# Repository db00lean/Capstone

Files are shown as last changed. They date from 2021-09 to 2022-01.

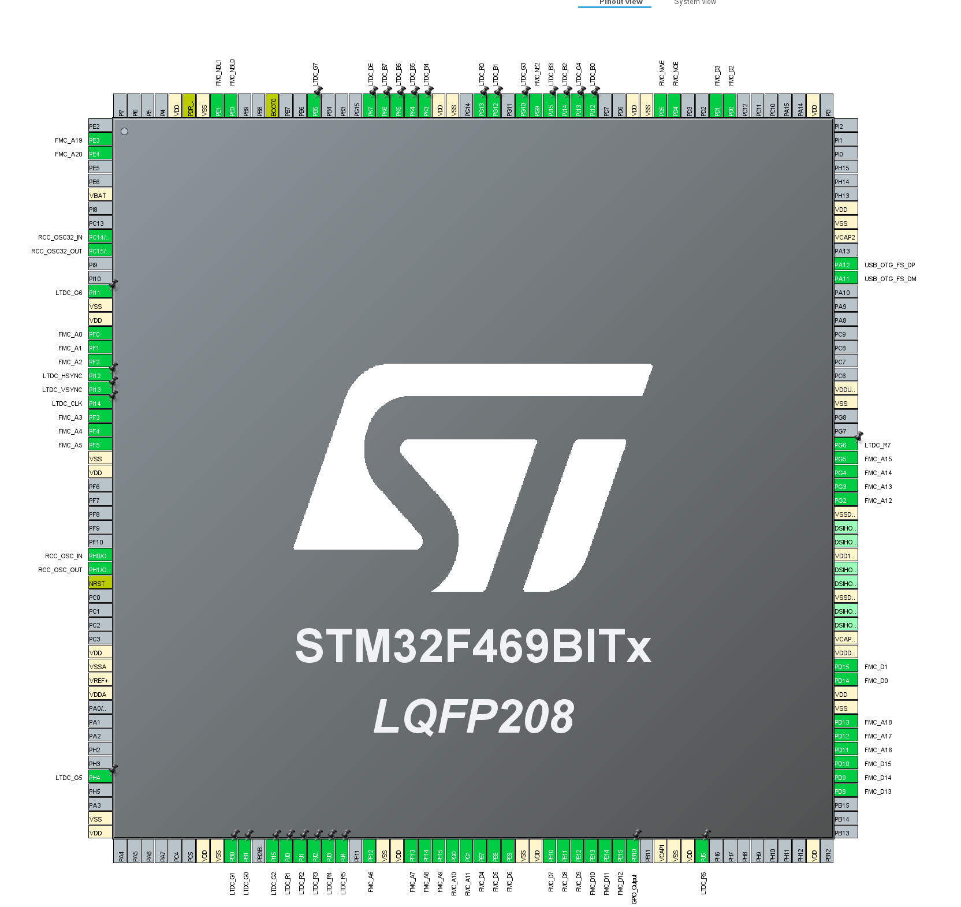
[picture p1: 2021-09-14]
Software/Resources/Pinout.PNG

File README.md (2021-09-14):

# Capstone
Fall 2021 Final Capstone Project

File System:
```
>Capstone
    >Software
        >Resources
        >CodeBase
    >Hardware
        >Library
            >Personal Library
            >Universal Converter Library
        >Resources
            >Datasheets
        >UniversalConverter
            > Altium Files
```

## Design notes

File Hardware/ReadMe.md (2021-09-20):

# Attention!
Please make sure all files upload, sometimes the drag and drop will neglect certain file extensions

Please do not change the file tree!

# Library:
Parts libraries used in Univseral Converter Altium project. These parts libraries contain all symbol and footprint files.

To install open the .libPkg file in Altium which will automatically open all the other files

# Resources:
Useful documentation for all things relating to hardware. Contains files like Datasheets, websites, and diagrams.

# Universal Converter
Core Altium project containing all files for the PCB and schematics. Do not change file structure

# LTSpice Simulations
All information regarding the research, planning, and execution for designing the power conversion circuitry around the LT3790 buck-boost converter.

Please Update Revision Number in text file name!

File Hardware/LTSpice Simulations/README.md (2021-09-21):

The core functionality of this project lies within the LT3790 buck-boost converter, which allows for high efficiency buck and boost operations on an input source within a specified range. To test the functionality of the IC without creating several PCB revs, we decided to run simulations to ensure "normal" operation of our circuitry prior to ordering boards.

To run the simulation, install LTSpice on your machine and pull the file ```Capstone/hardware/LTSpice Simulations/LT3790_Rev_A.asc```. This is the base simulation file from Linear Technologies for the LT3790 converter. We will build upon this in future revs.

# Simulation Tasks
There are several subtasks within simulating the LT3790 needed to design a fully-functional system that meets our desired goal.

## Understanding The Datasheet
It is vital that all electrical hardware engineers understand the LT3790 datasheet. 
The datasheet is located at ```Capstone/hardware/resources/LT3790_datasheet.pdf```

## Switching Component Selection
For the most efficient operation within our specified ranges of input/output voltage and current, 
we must select appropriate switching MOSFETs and inductors with minimum Rdson and and high enough 
inductor SRF that our maximum switching frequency does not cause the inductor to self-resonate. More to come.

## Current/Voltage Limit Circuitry
The actual circuitry in this portion of the design will differ from the simulation, but we need
to understand how we can modify the voltage and current limits in real-time to adjust our output and 
effectively achieve the universal converter operation. If we can find a way to run code through the 
LTSpice simulation, we may be able to model how the firmware will integrate with the LT3790.

## External Converter Component Selection
A much easier task as we can use what is provided in the component selection portion of the datasheet to
select additional external components around the LT3790.

## Add A Second Converter
For dual-output, we need to add a second converter in the output path of the first. More to come after
fully simulating the base design.

## Add Remaining External Components
Aside from the MCU and firmware related components, we also can simulate the other ICs and components within 
the main power path. More to come.

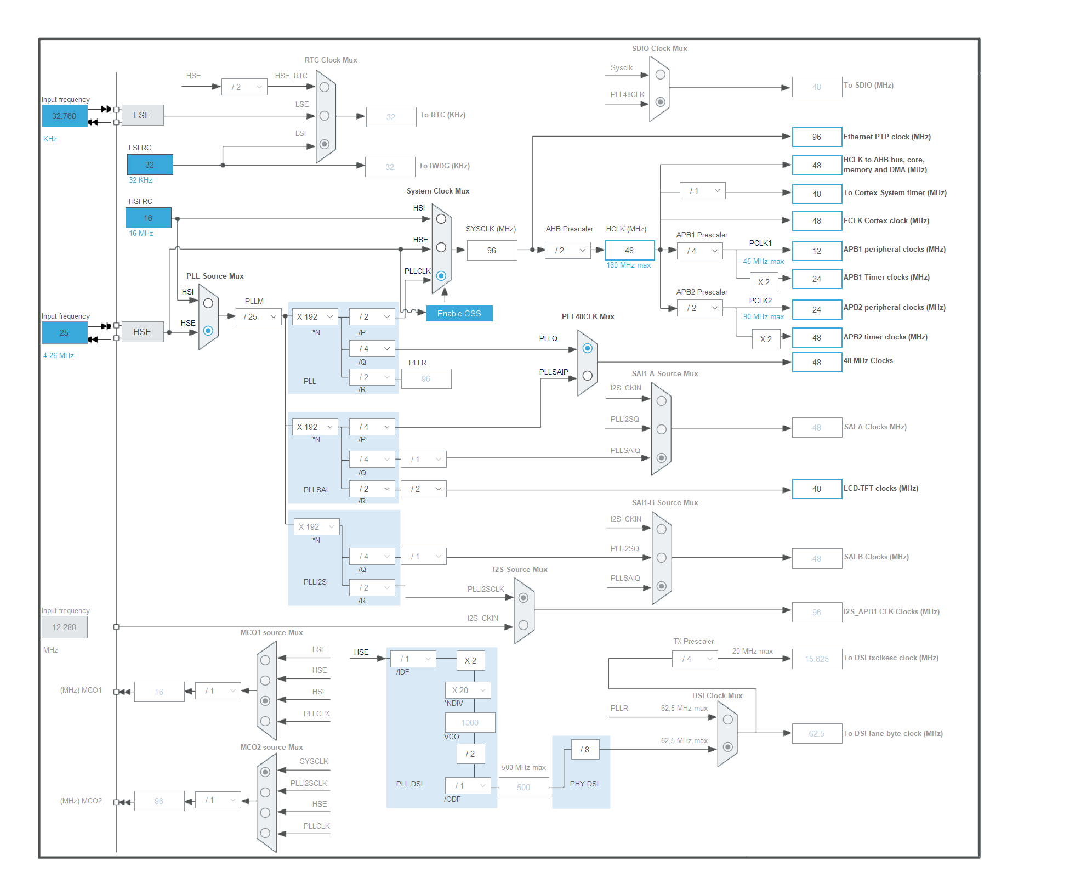
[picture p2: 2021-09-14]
Software/Resources/ClockDiagram.PNG

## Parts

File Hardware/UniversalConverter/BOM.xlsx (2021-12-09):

Part Number | Manufacturer | Description | Reference | Price | per board | STOCK | Link
SQJA80EP-T1_GE3TR-ND | Vishay Siliconix | MOSFET N-CH 80V 60A PPAK SO-8 |  | $1.26 | 11 | 10 | https://www.digikey.com/en/products/detail/vishay-siliconix/SQJA80EP-T1-GE3/6708932
SK58L-TPMSTR-ND | Micro Commercial Co | DIODE SCHOTTKY 80V 5A DO214AB |  | $0.48 | 4 | 5
LT3790IFE#TRPBF | Linear Tech | IC REG CTRLR BUCK-BOOST 38TSSOP |  | $11.53 | 2 | 3
HMK325BJ475KM-PE | Taiyo Yuden | CAP CER 4.7UF 100V X5R 1210 |  | $1.08 | 30 | 12
1727-4817-2-ND |  | DIODE SCHOTTKY 100V 250MA SOD323 |  | $0.38 | 4 | 3
732-2174-2-ND | Würth Elektronik | FIXED IND 6.8UH 18.5A 4.1MOHM SM |  | $5.53 | 2 | 2
296-44514-5-ND | Texas Instruments | IC REG BUCK ADJUSTABLE 3A 8SOPWR |  | $4.89 | 1 | 10
B380B-13-FDITR-ND | Diodes Incorporated | Diode Schottky 80 V 3A Surface Mount SMB |  | $0.91 | 1 | 0
732-1207-2-ND | Würth Elektronik | FIXED IND 8.2UH 6.25A 20MOHM SMD |  | $2.19 | 1 | 2
EEE-FN1K100XL | Panasonic Electronic Components | CAP ALUM 10UF 20% 80V SMD |  | $0.66 | 11 | 32
296-41943-5-ND | Texas Instruments | IC REG LIN 3.3V 500MA SOT223-6 |  | $4.49 | 1 | 5
LTC4359CMS8#TRPBFTR-ND | Analog Devices Inc. | IC OR CTRLR N+1 8MSOP |  | $4.61 | 4 | 3
LMP8480MME-S/NOPBTR-ND | Texas Instruments | IC CURR SENSE 1 CIRCUIT 8VSSOP |  | $3.34 | 3 | 6
CRF2512-FZ-R001ELFTR-ND | Bourns Inc. | RES 0.001 OHM 1% 2W 2512 |  | $0.67 | 3 | 3
MCP4017T-104E/LTTR-ND | Microchip Technology | IC DGT POT 100KOHM 128TAP SC70-6 |  | $0.63 | 2 | 5
10-EEE-FN1K470UVCT-ND | Panasonic Electronic Components | CAP ALUM 47UF 20% 80V SMD |  | $1.24 | 10 | 10
CRF2512-FZ-R004ELFTR-ND | Bourns Inc. | RES 0.004 OHM 1% 2W 2512 |  | $0.67 | 2 | 2
CRE2512-FZ-R005E-2TR-ND | Bourns Inc. | RES 0.005 OHM 1% 2W 2512 |  | $0.74 | 2 | 2
WSLH-.006TR-ND | Vishay Dale | RES 0.006 OHM 1% 2W 2512 |  | $1.76 | 2 | 2
RHM.007AUTR-ND | Rohm Semiconductor | RES 0.007 OHM 1% 2W 2512 |  | $0.70 | 2 | 2
CRE2512-FZ-R008E-2TR-ND | Bourns Inc. | RES 0.008 OHM 1% 2W 2512 |  | $0.74 | 2 | 2
YAG2163TR-ND | YAGEO | RES 0.009 OHM 1% 2W 2512 |  | $0.73 | 2 | 2
FSM6JSMATR | TE Connectivity | SWITCH TACTILE SPST-NO 0.05A 24V |  | $0.41 | 4
10118194-0001LF | Amphenol ICC (FCI) | CONN RCPT USB2.0 MICRO B SMD R/A |  | $0.45 | 1
RCLAMP0854P.TCTCT-ND | Semtech Corporation | TVS DIODE 5.5VWM 30VC SLP1616P6 |  | $0.94 | 1
296-15227-1-ND | Texas Instruments | IC DAC 12BIT V-OUT 10VSSOP |  | $8.30 | 1
PEC12R-4025F-S0024 | Bourns Inc. | ROTARY ENCODER MECHANICAL 24PPR |  | $1.31 | 1
497-4941-1-ND | STMicroelectronics | IC OPAMP GP 1 CIRCUIT SOT23-5 |  | $0.63 | 2
SK58L-TPMSCT-ND | Micro Commercial Co | DIODE SCHOTTKY 80V 5A DO214AB |  | $0.48 | 5
XC1846CT-ND | ECS Inc. | CRYSTAL 32.0000MHZ 8PF SMD |  | $1.01 | 1
300-8814-2-ND | Citizen Finedevice Co Ltd | CRYSTAL 32.7680KHZ 12.5PF SMD |  | $0.72 | 1
EG5468CT-ND | E-Switch | SWITCH TACTILE SPST-NO 0.05A 12V |  | $0.46 | 4
NHD-2.7-12864WDW3 | Newhaven Display Intl | LCD OLED GRAPHIC 128X64 WHT |  | $42.58 | 1
296-15227-1-ND | Texas Instruments | IC DAC 12BIT V-OUT 10VSSOP |  | $8.30 | 1
497-17515-ND | STMicroelectronics | IC MCU 32BIT 128KB FLASH 48LQFP |  | $6.32 | 1 | 4
111-0703-001 | Cinch Connectivity | CONN BIND POST KNURLED BLACK |  | $3.09 | 3
111-0702-001 | Cinch Connectivity | CONN BIND POST KNURLED RED |  | $3.09 | 3
541-0.0GCT-ND | Vishay Dale | RES SMD 0 OHM JUMPER 1/10W 0603 |  | $0.10 | 10
RMCF0603FT10K0CT-ND | Stackpole Electronics Inc | RES 10K OHM 1% 1/10W 0603 |  | $0.10 | 10
P200KGCT-ND | Panasonic Electronic Components | RES SMD 200K OHM 5% 1/10W 0603 |  | $0.10 | 10
445-5663-1-ND | TDK Corporation | CAP CER 0.022UF 50V X7R 0603 |  | $0.10 | 5
1276-CL10B104KB8NNNLCT-ND | Samsung Electro-Mechanics | CAP CER 0.1UF 50V X7R 0603 |  | $0.10 | 15
13-RE0603FRE071KLCT-ND | YAGEO | RES SMD 1K OHM 1% 1/10W 0603 |  | $0.10 | 5
641-1713-1-ND | Comchip Technology | DIODE SCHOTTKY 60V 1A DO214AA |  | $0.35 | 3
RMCF0603FT49K9CT-ND | Stackpole Electronics Inc | RES 49.9K OHM 1% 1/10W 0603 |  | $0.10 | 2
311-17.8KHRCT-ND | YAGEO | RES 17.8K OHM 1% 1/10W 0603 |  | $0.10 | 2
13-RE0603FRE07100KLCT-ND | YAGEO | RES SMD 100K OHM 1% 1/10W 0603 |  | $0.10 | 10
1763-1218-ND | Knowles Novacap | CAP CER 0.1UF 50V X7R 0805 EPOXY |  | $1.21 | 2
478-10560-1-ND | KYOCERA AVX | CAP CER 5000PF 50V X7R 0805 |  | $0.30 | 2
CR0603-FX-4321ELFCT-ND | Bourns Inc. | RES SMD 4.32K OHM 1% 1/10W 0603 |  | $0.10 | 2
311-1057-1-ND | YAGEO | CAP CER 8PF 50V C0G/NPO 0603 |  | $0.10 | 2

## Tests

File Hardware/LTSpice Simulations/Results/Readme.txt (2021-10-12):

The Inductor/Switching Frequency simulations are designed as follows:

Input: 5V
Output: 60V

Switching Frequencies of 200KHz to 700KHz in 100KHz intervals will be tested by changing the value
of the resistor on the Rt pin. The inductor will remain constant for each set of frequency tests.

A higher switching frequency should allow smaller inductor/capacitor values at the cost of increased switching losses and gate driving current.

A lower switching frequency should give better performance at the cost of large component sizes.

Required Plots:

-Output Voltage: Larger inductor values arise from lower switching frequencies, but have a direct effect on the ripple current.

-Gate Currents: Higher Switching frequencies will create larger gate driving currents, so each plots needs to show the gate currents of each of the four Power MOSFETs. These need to be tested and ensured that they're below the maximum specification of the FETs we purchased.

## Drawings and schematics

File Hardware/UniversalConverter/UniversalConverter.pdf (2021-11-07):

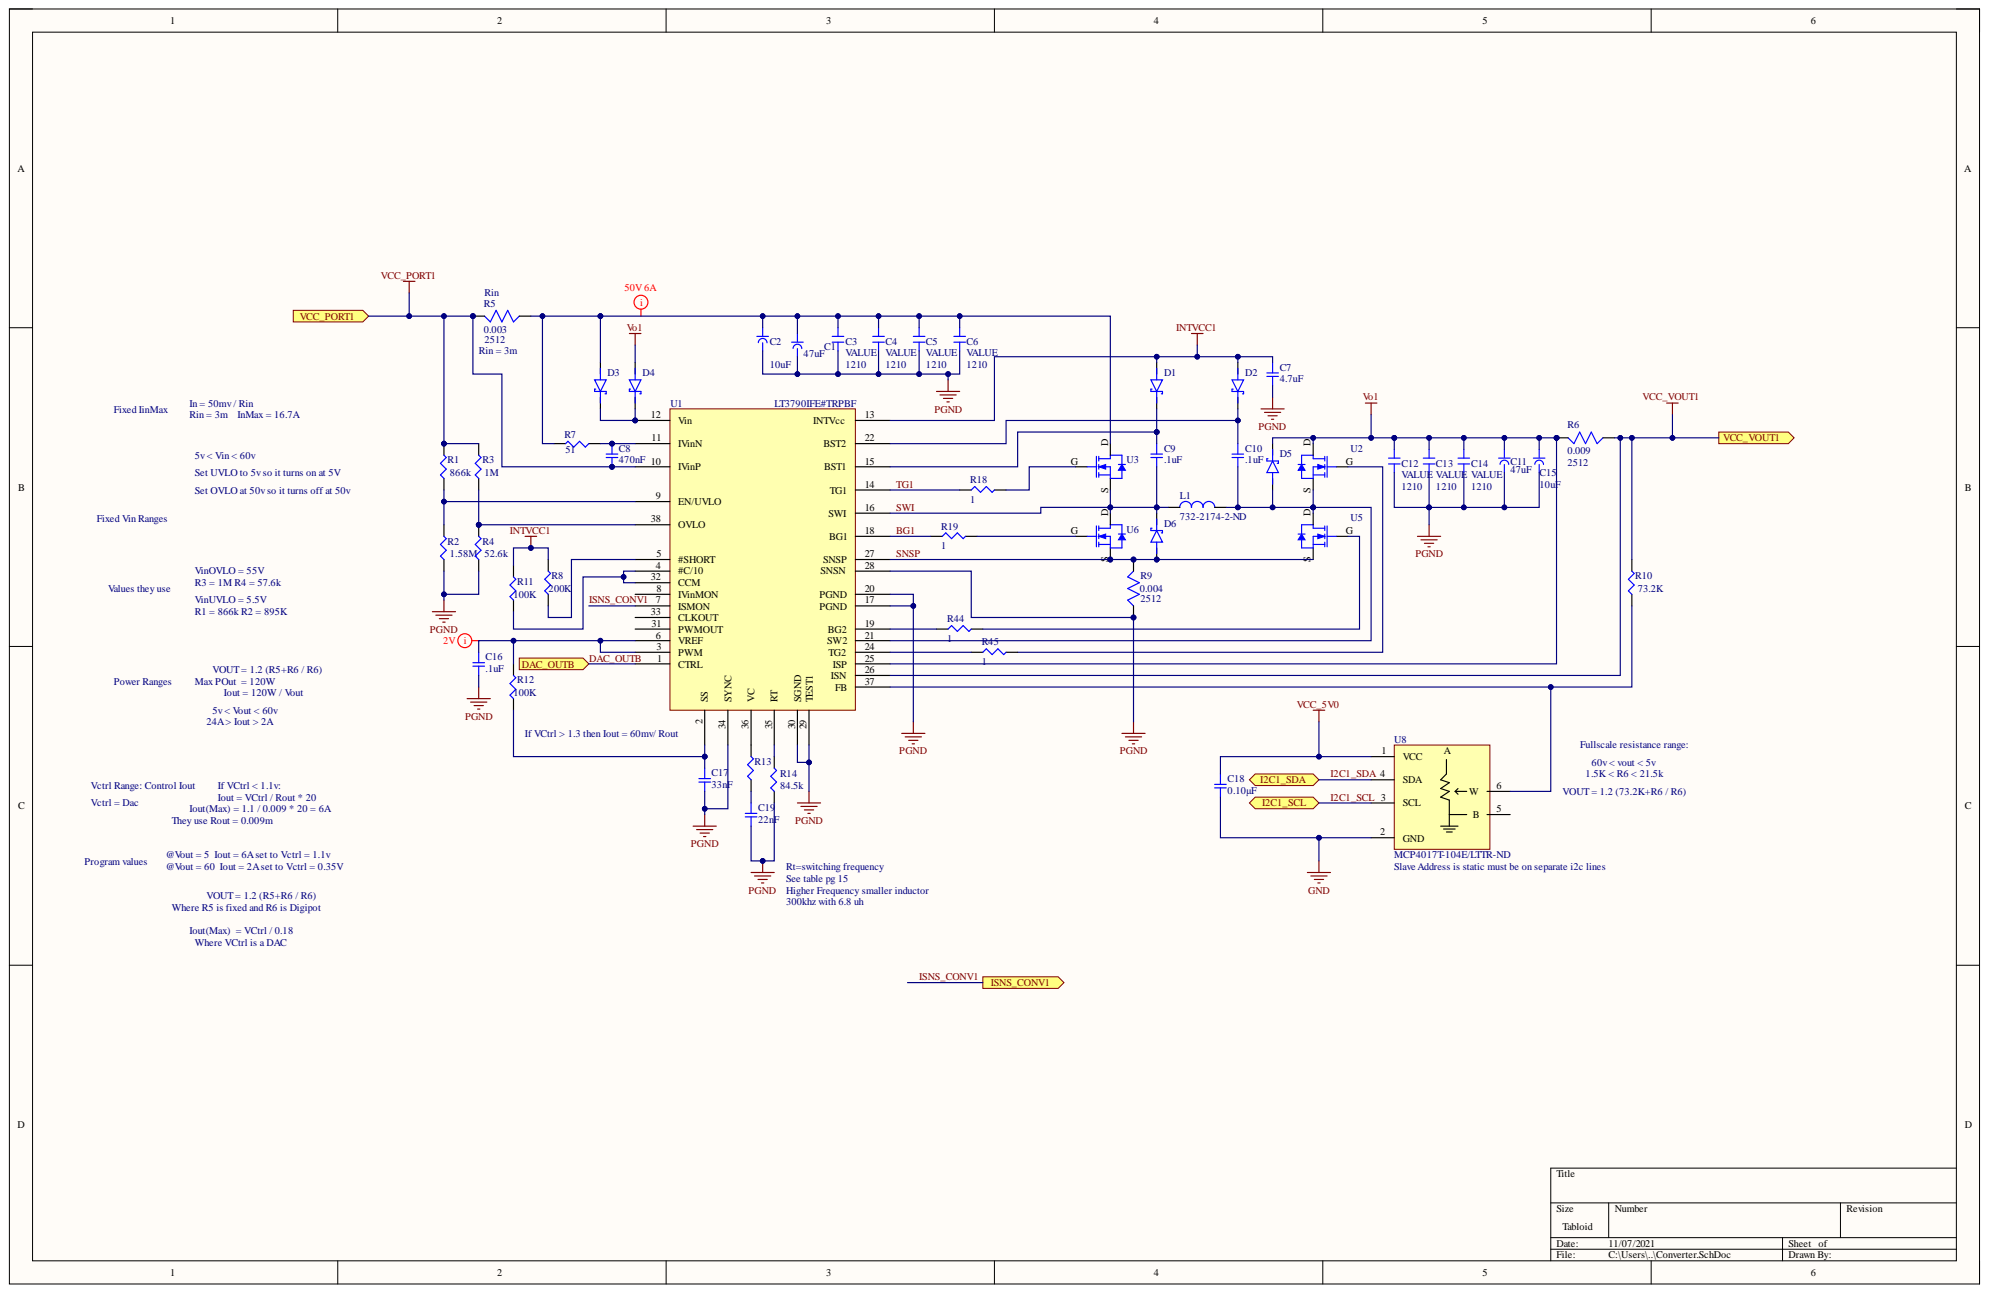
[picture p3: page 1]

In = 50mv / Rin Fixed IinMax

Set UVLO to 5v so it turns on at 5V

Set OVLO at 50v so it turns off at 50v

INTVCC1 | #SHORT 5

OVLO 38

VCC_5V0

If VCtrl > 1.3 then Iout = 60mv/ Rout

I2C1_SDA | SDA 4

Vctrl Range: Control Iout

@Vout = 5 Iout = 6Aset to Vctrl = 1.1v
@Vout = 60 Iout = 2Aset to Vctrl = 0.35V

MCP4017T-104E/LTTR-ND
Slave Address is static must be on separate i2c lines

Rt=switching frequency
See table pg 15
Higher Frequency smaller inductor
300khz with 6.8 uh

Where R5 is fixed and R6 is Digipot

Iout(Max) = VCtrl / 0.18
Where VCtrl is a DAC

Size Tabloid | Number | Revision

Date: 11/07/2021 | Sheet of
File: C:\Users\..\Converter.SchDoc | Drawn By:

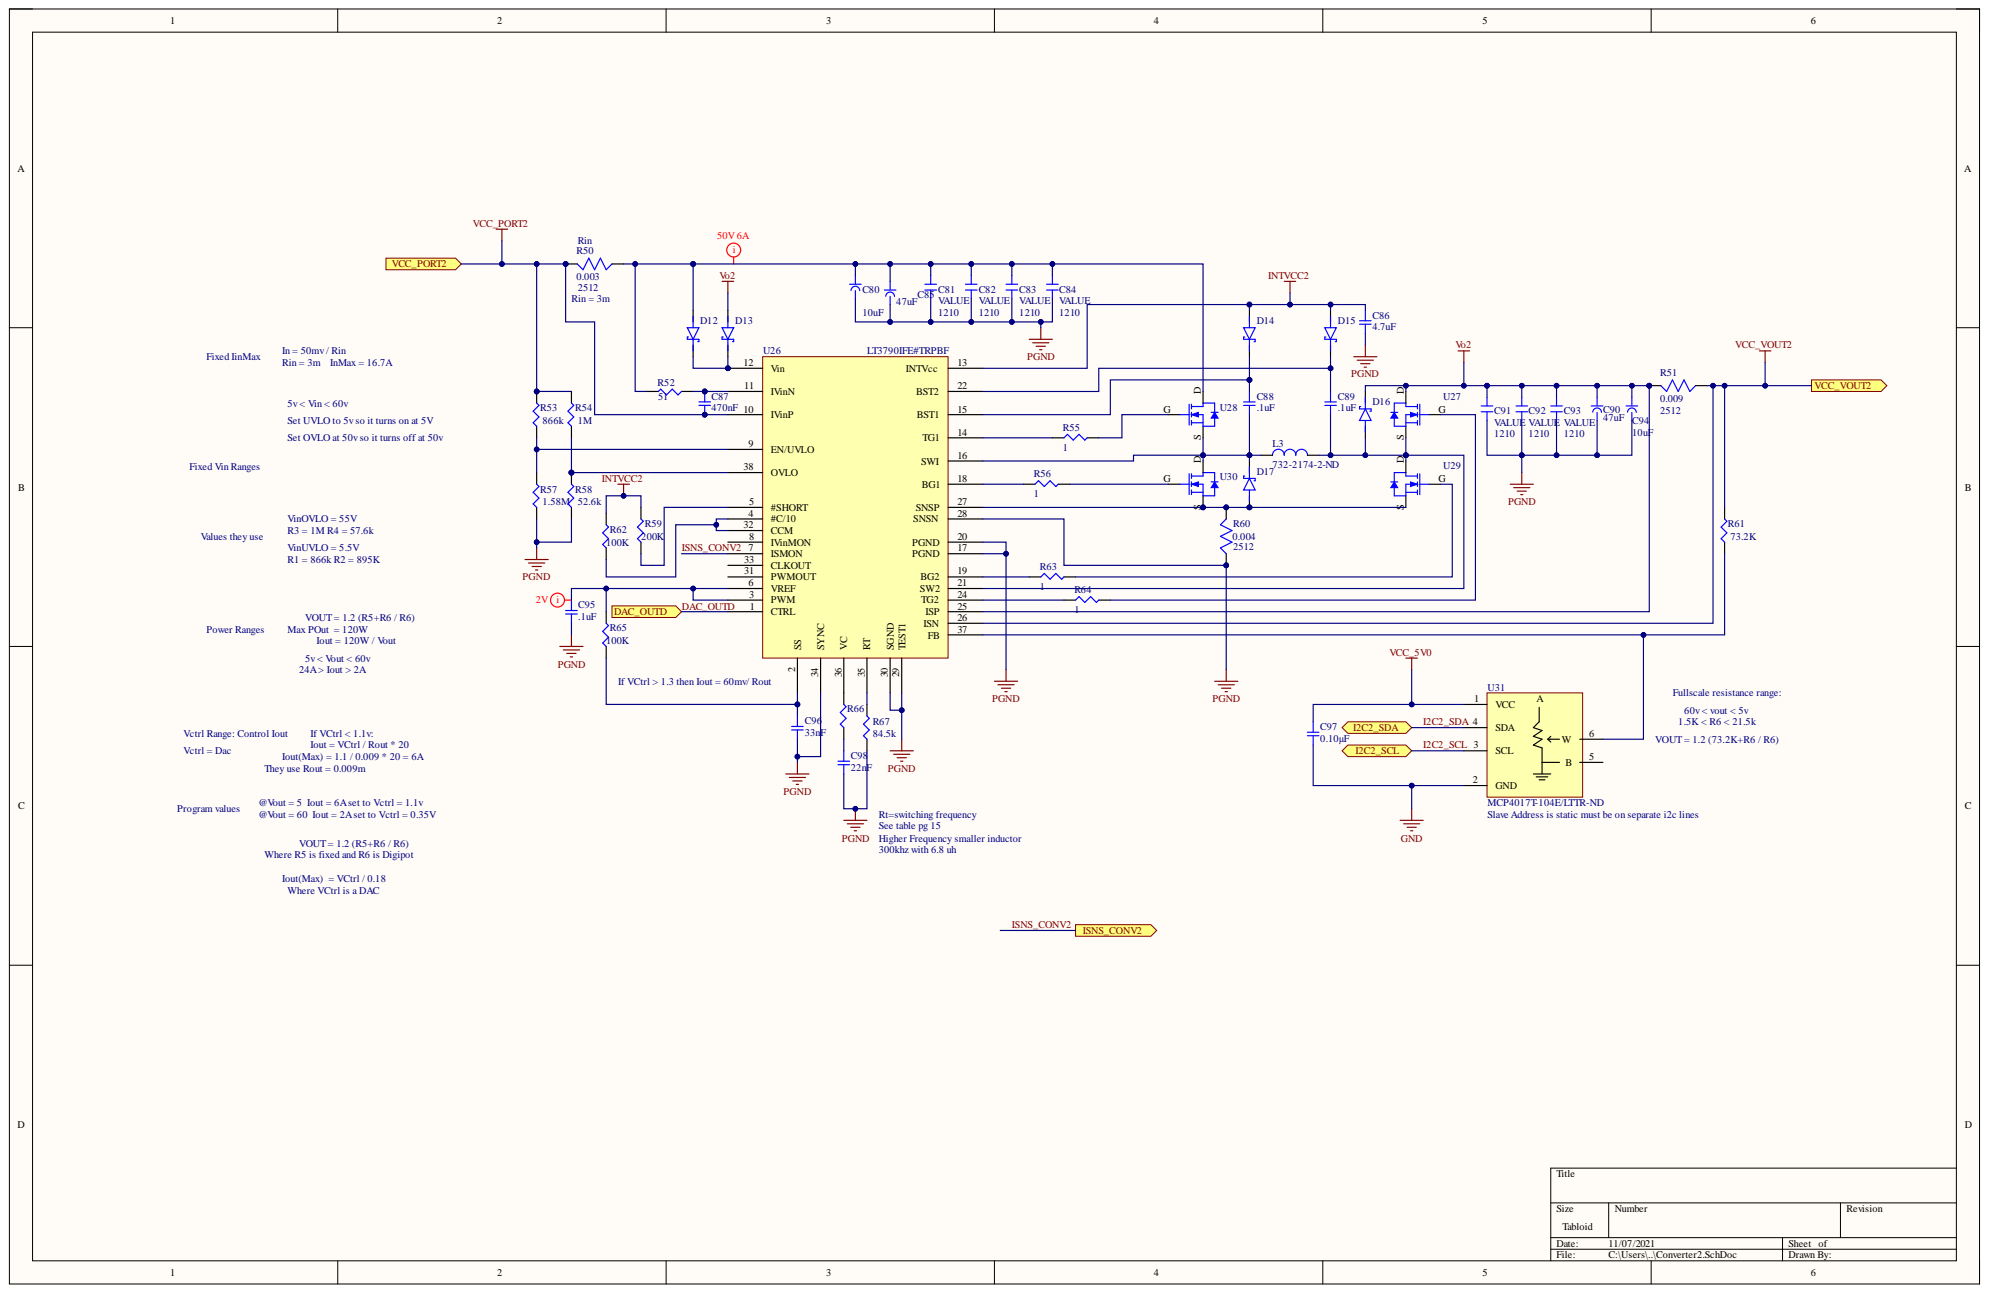
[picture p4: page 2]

In = 50mv / Rin Fixed IinMax

Set UVLO to 5v so it turns on at 5V

Set OVLO at 50v so it turns off at 50v

VCC_5V0

If VCtrl > 1.3 then Iout = 60mv/ Rout

Vctrl Range: Control Iout

I2C2_SDA | SDA 4

@Vout = 5 Iout = 6Aset to Vctrl = 1.1v
@Vout = 60 Iout = 2Aset to Vctrl = 0.35V

Rt=switching frequency
See table pg 15
Higher Frequency smaller inductor
300khz with 6.8 uh

MCP4017T-104E/LTTR-ND
Slave Address is static must be on separate i2c lines

Where R5 is fixed and R6 is Digipot

Iout(Max) = VCtrl / 0.18
Where VCtrl is a DAC

Size Tabloid | Number | Revision

Date: 11/07/2021 | Sheet of
File: C:\Users\..\Converter2.SchDoc | Drawn By:

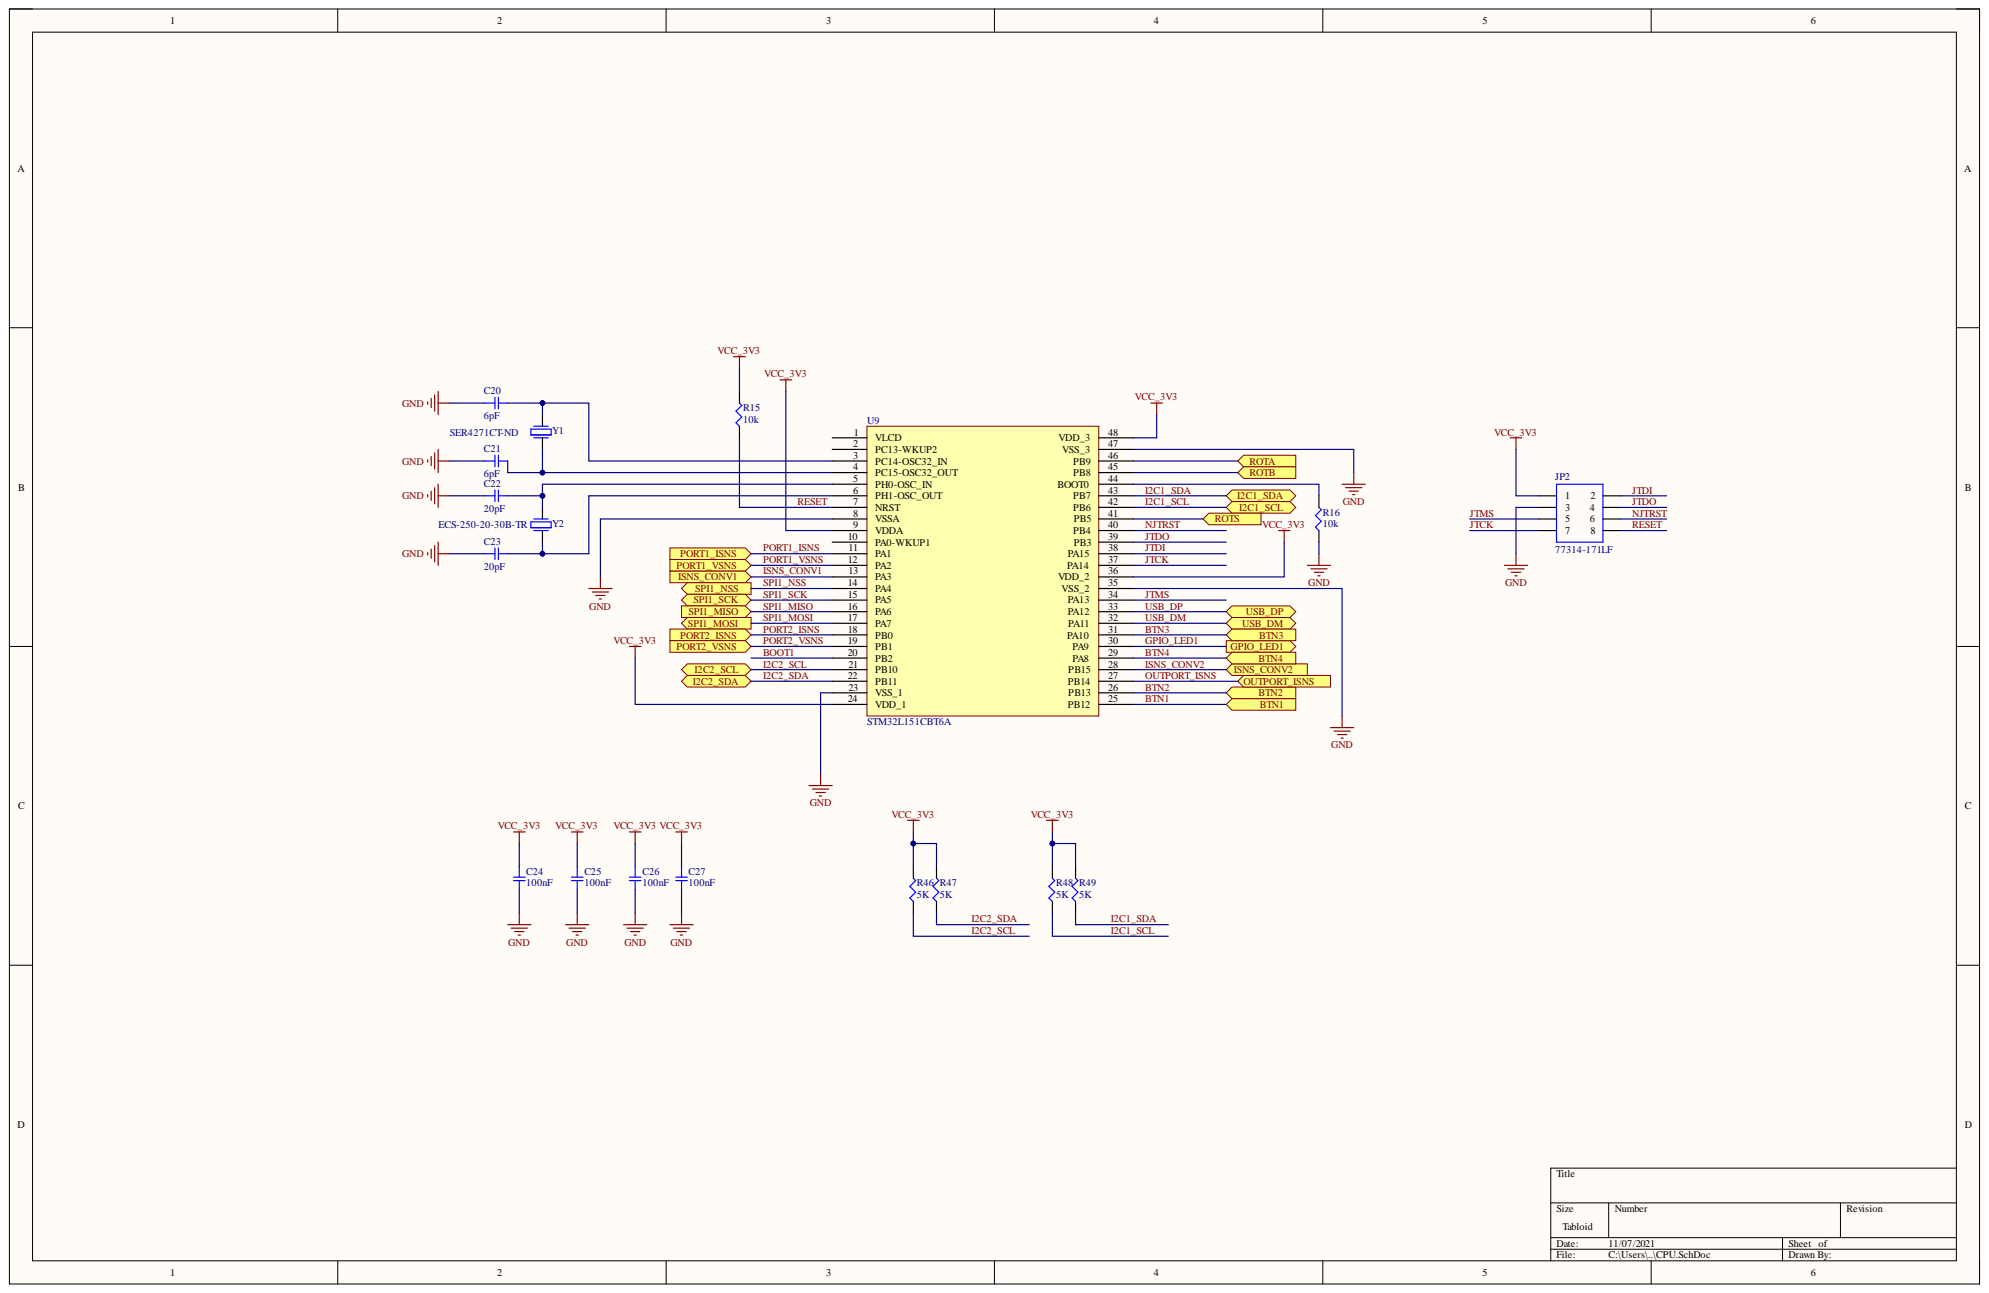
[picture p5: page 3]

2 | | 4 7
3 | | 4 6 4 5 | R O TA
5 | | 4 4

J TMS U S B _ D P U S B _ D P U S B _ D M U S B _ D M B TN 3 B TN 3 G P I O _ L E D 1 G P I O _ L E D 1 B TN 4 4 I S N S _ C O N V2 O U TP O RT_ I S N S I S N S _ C O N V2 O U TP O RT_ I S N S B TN 2 B TN 1 B TN 2 B TN 1

S i z e Tab l o i d | N u mb e r | R e vi s i o n

D at e : 1 1 / 0 7 / 2 0 2 1 | S h e e t o f
Fi l e : C : \ U s e r s \ . . \ C P U . S c hD o c | D r awn B y :

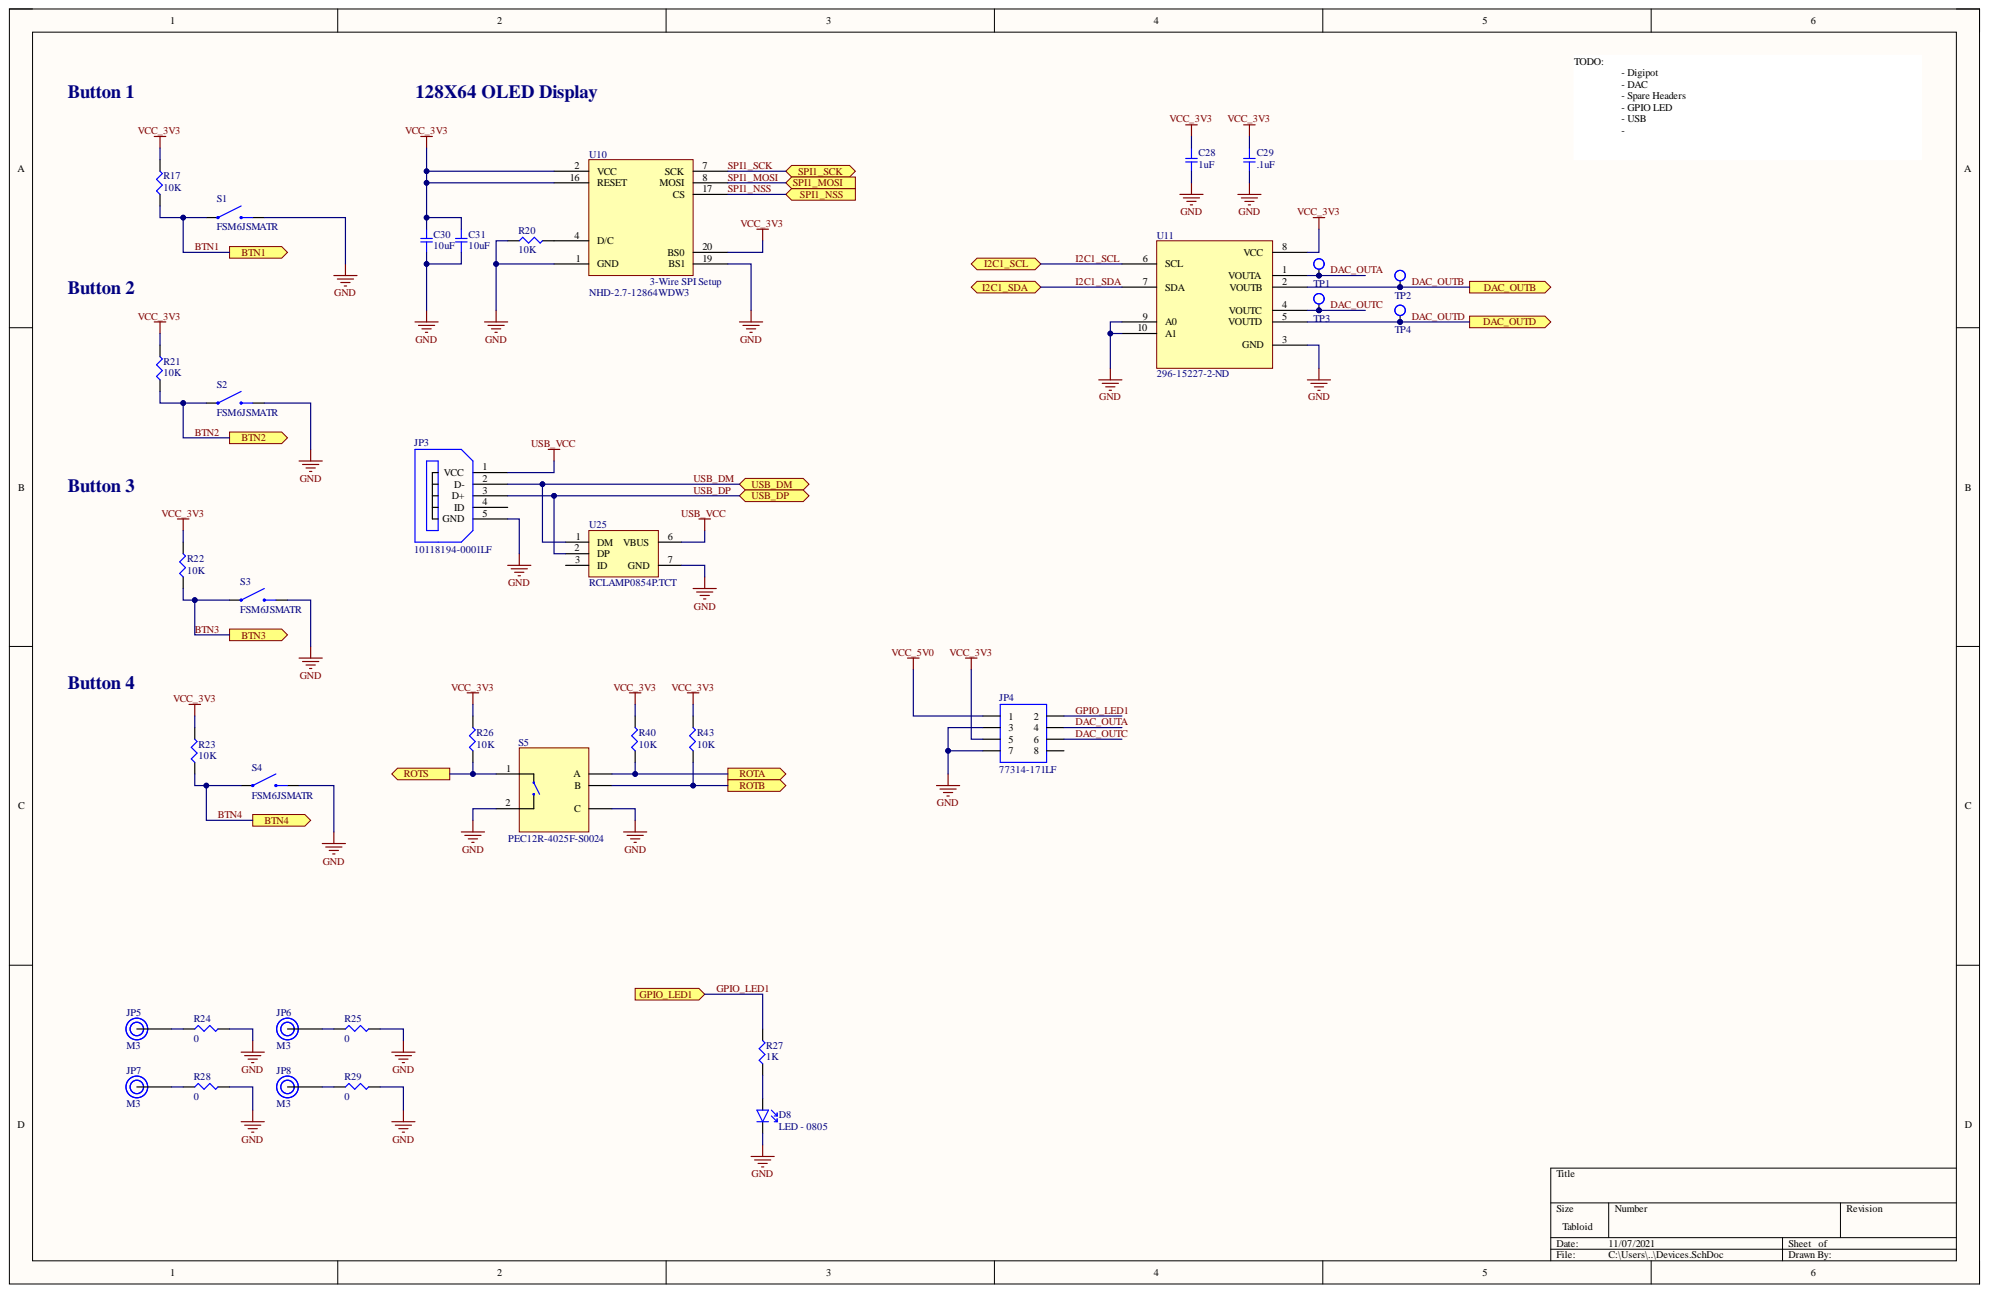
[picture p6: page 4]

Size Tabloid | Number | Revision

Date: 11/07/2021 | Sheet of
File: C:\Users\..\Devices.SchDoc | Drawn By:

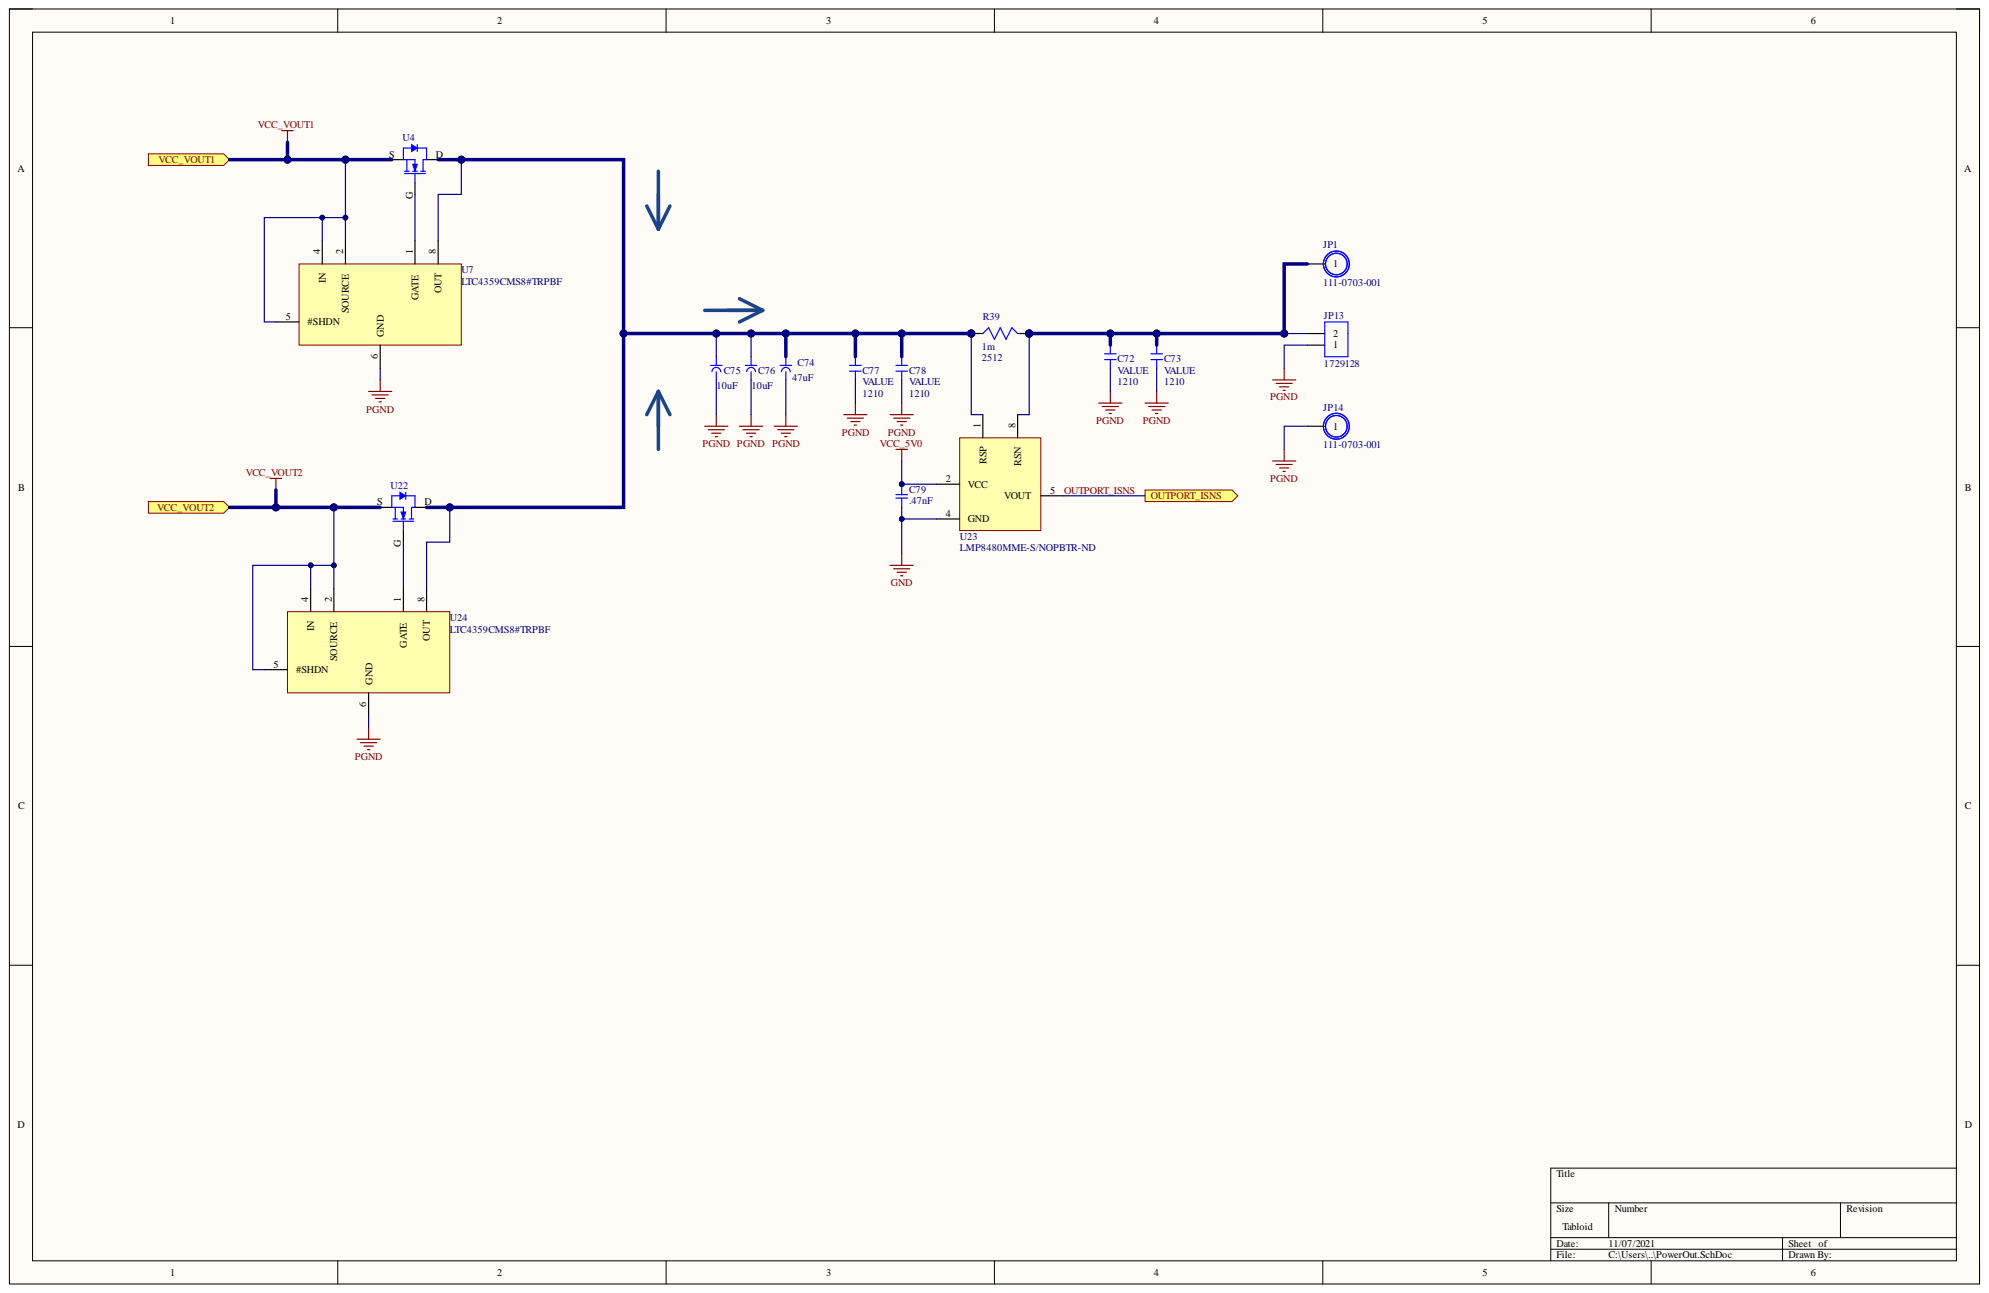
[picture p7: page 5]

Size Tabloid | Number | Revision

Date: 11/07/2021 | Sheet of
File: C:\Users\..\PowerOut.SchDoc | Drawn By:

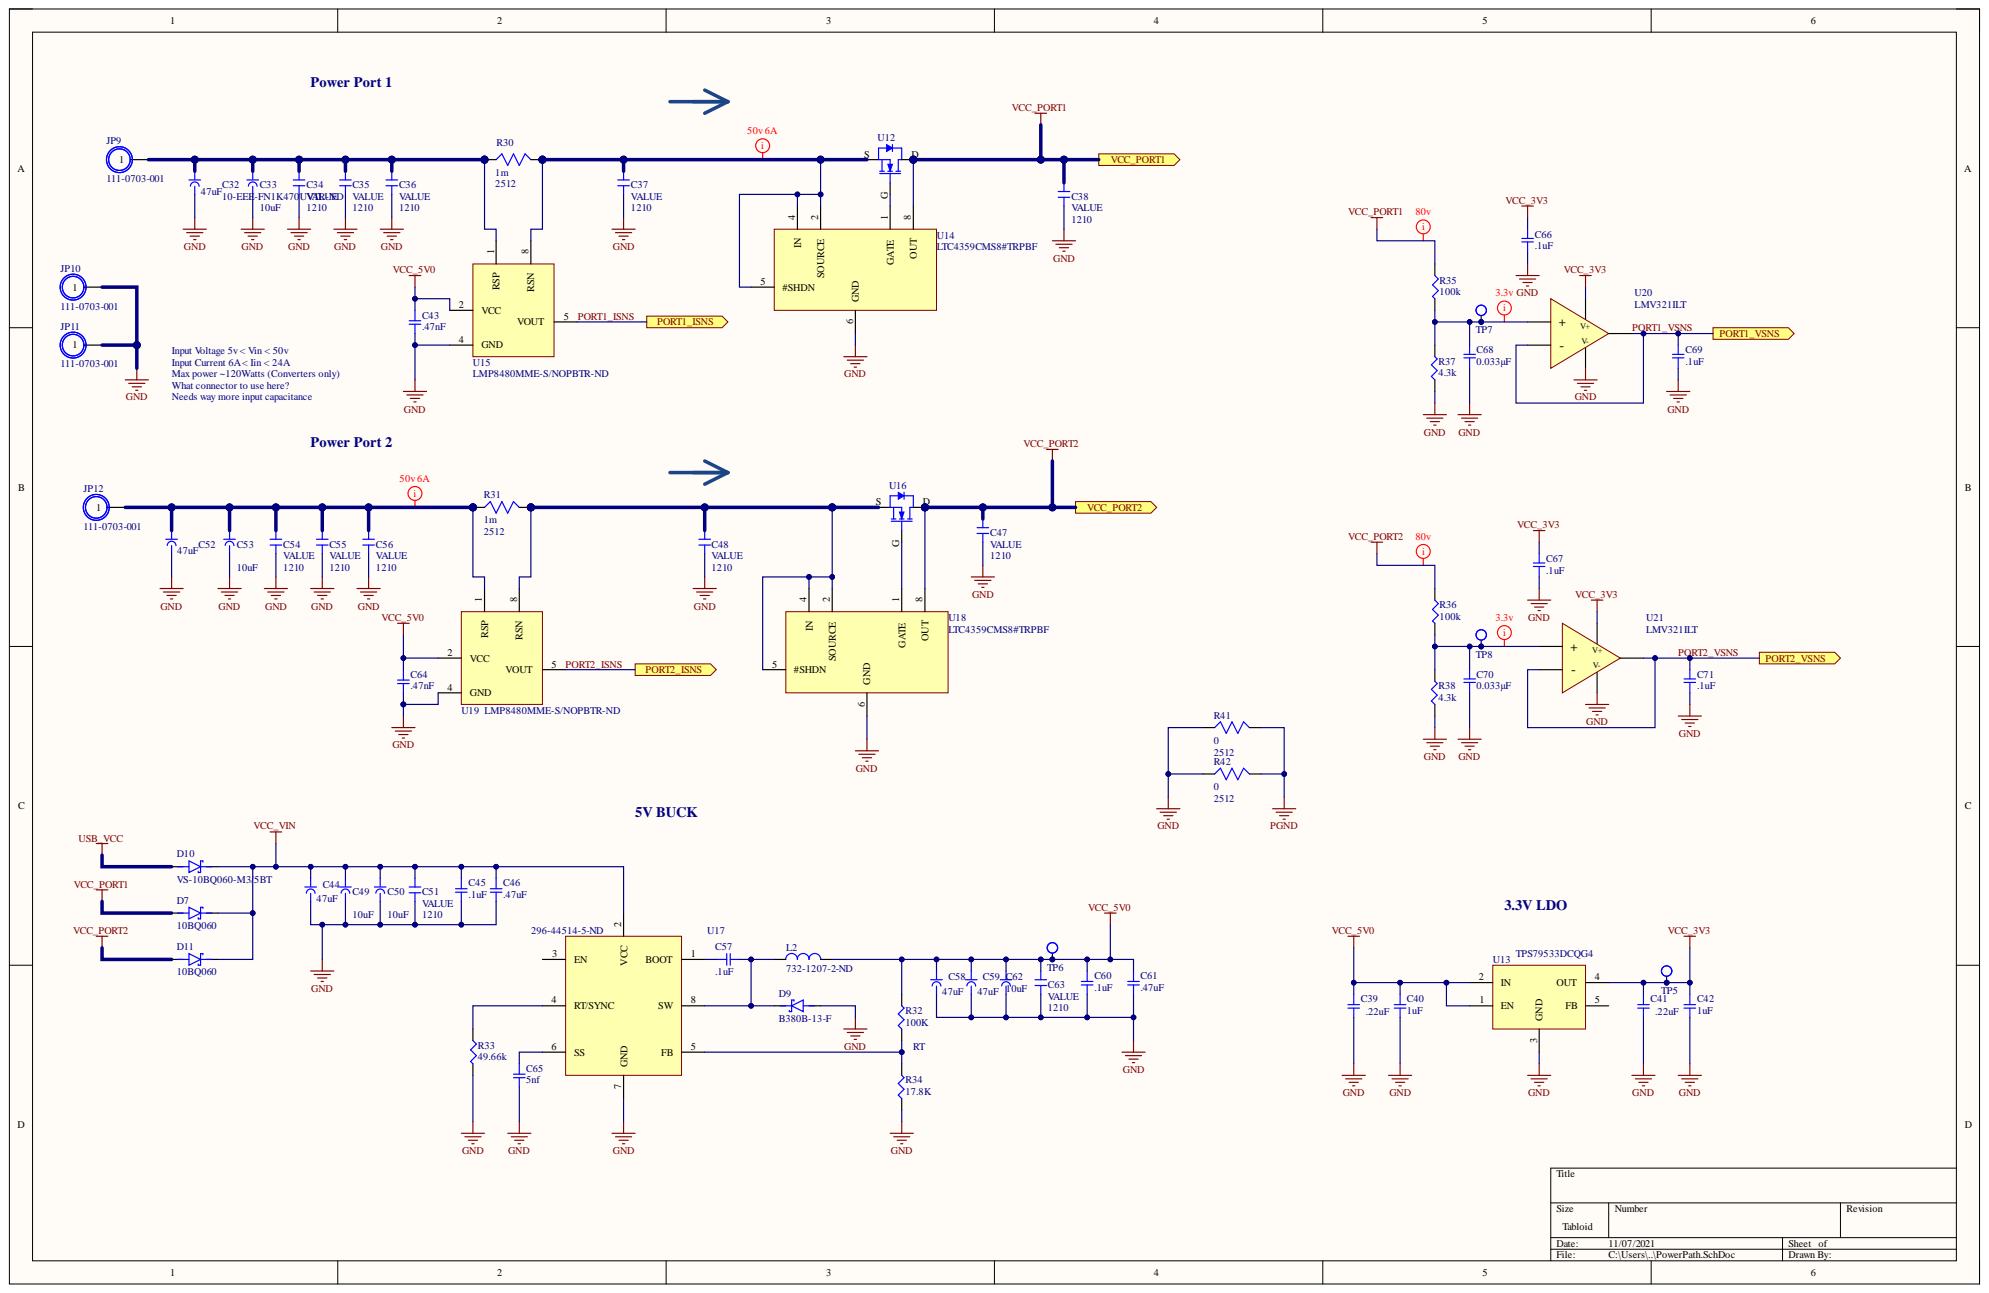
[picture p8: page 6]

Input Voltage 5v < Vin < 50v
Input Current 6A< Iin < 24A
Max power ~120Watts (Converters only)
What connector to use here?
Needs way more input capacitance

Size Tabloid | Number | Revision

Date: 11/07/2021 | Sheet of
File: C:\Users\..\PowerPath.SchDoc | Drawn By:

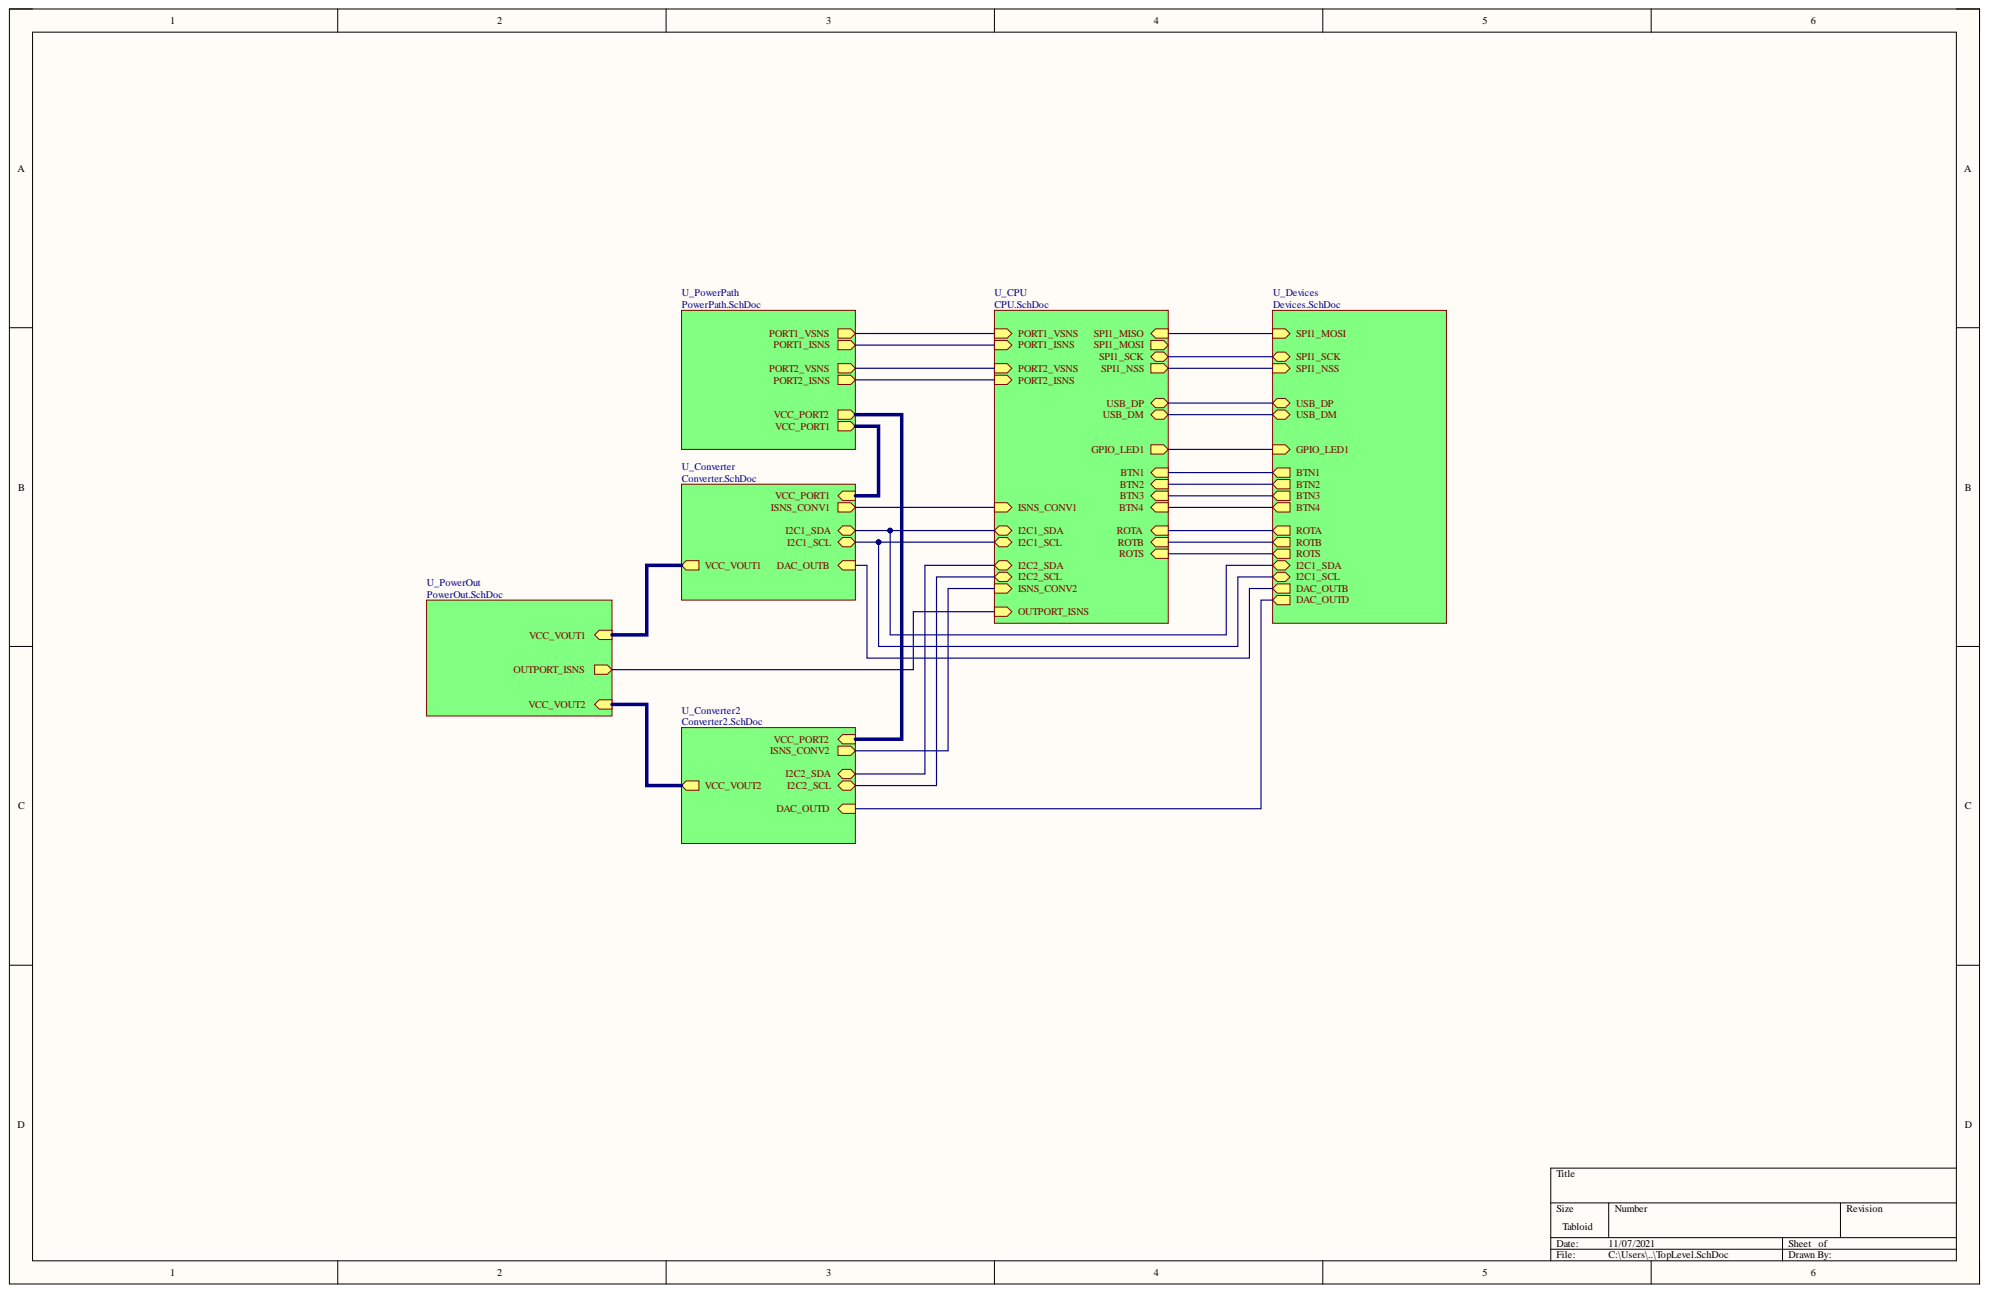
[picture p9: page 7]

I2C1_SCL ROTB
ROTS I2C2_SDA I2C2_SCL ISNS_CONV2

VCC_VOUT1 OUTPORT_ISNS VCC_VOUT2 | | OUTPORT_ISNS

Size Tabloid | Number | Revision

Date: 11/07/2021 | Sheet of
File: C:\Users\..\TopLevel.SchDoc | Drawn By:

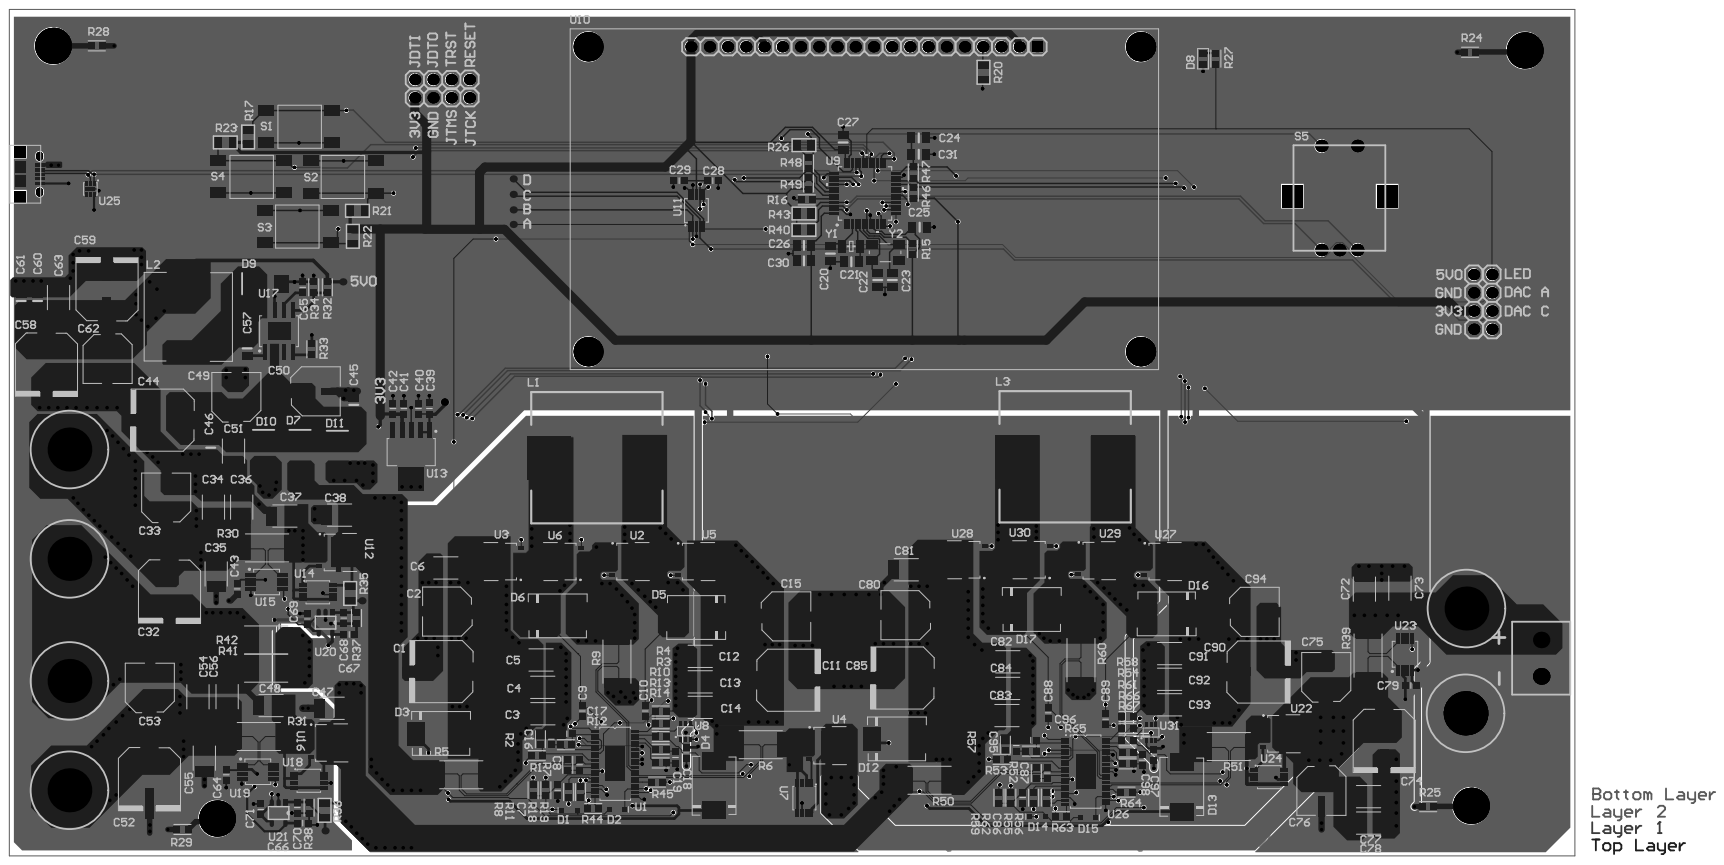
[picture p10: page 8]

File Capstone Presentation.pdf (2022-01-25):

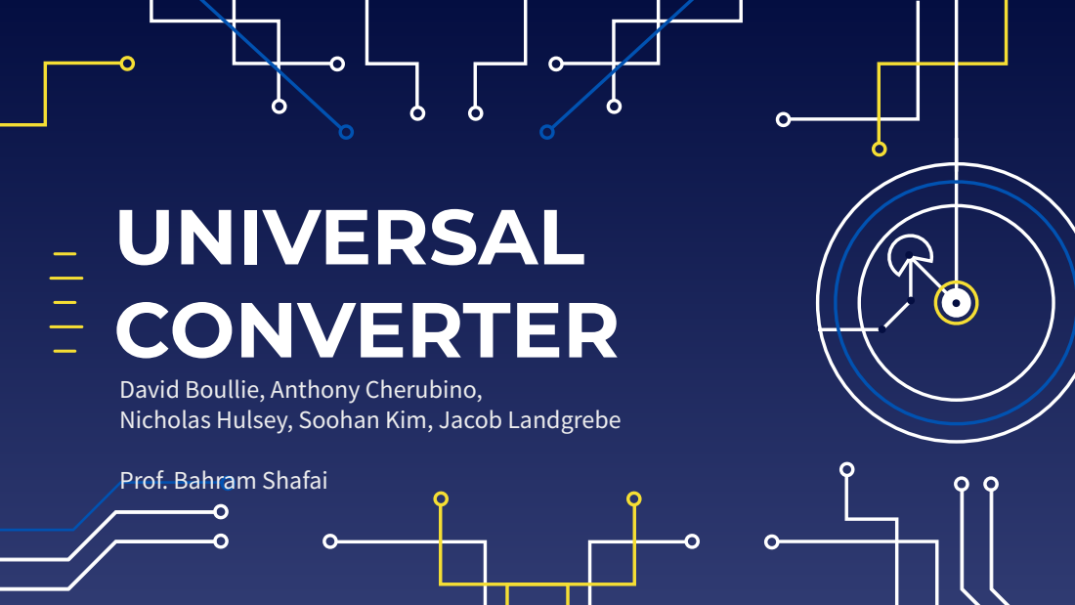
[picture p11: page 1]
UNIVERSAL CONVERTER

David Boullie, Anthony Cherubino,
Nicholas Hulsey, Soohan Kim, Jacob Landgrebe

Prof. Bahram Shafai

# Configurable Power Conversion

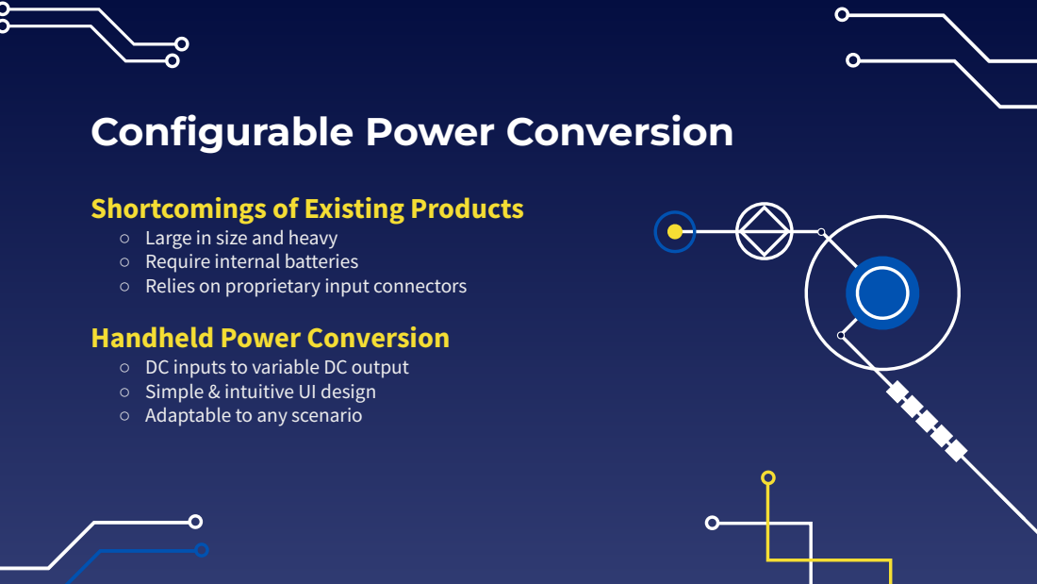
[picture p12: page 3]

Shortcomings of Existing Products
○ Large in size and heavy
○ Require internal batteries
○ Relies on proprietary input connectors
Handheld Power Conversion
○ DC inputs to variable DC output
○ Simple & intuitive UI design
○ Adaptable to any scenario

# GOALS

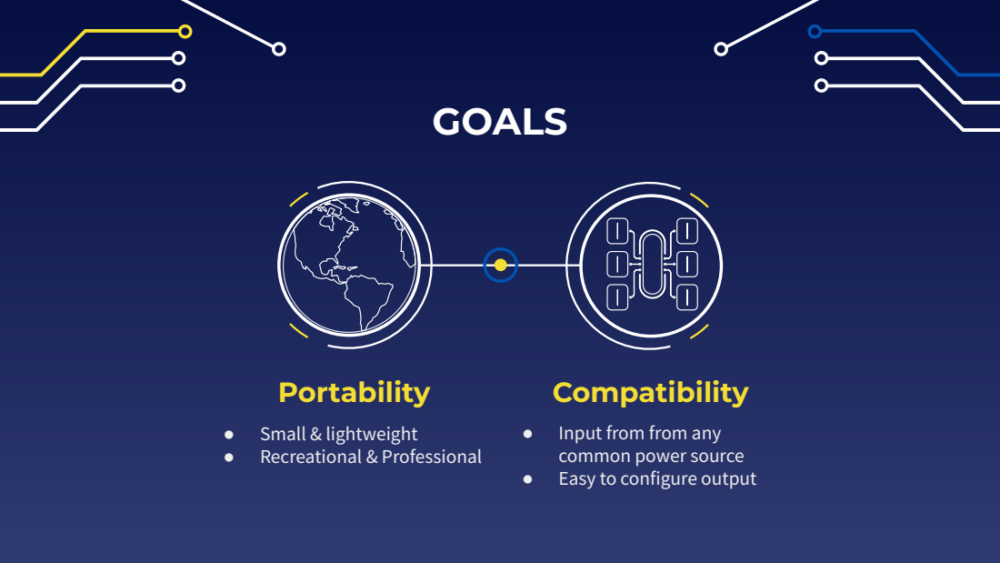
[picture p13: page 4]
Portability; ● Small & lightweight ● Recreational & Professional; Compatibility

● Input from from any
common power source
● Easy to configure output

02

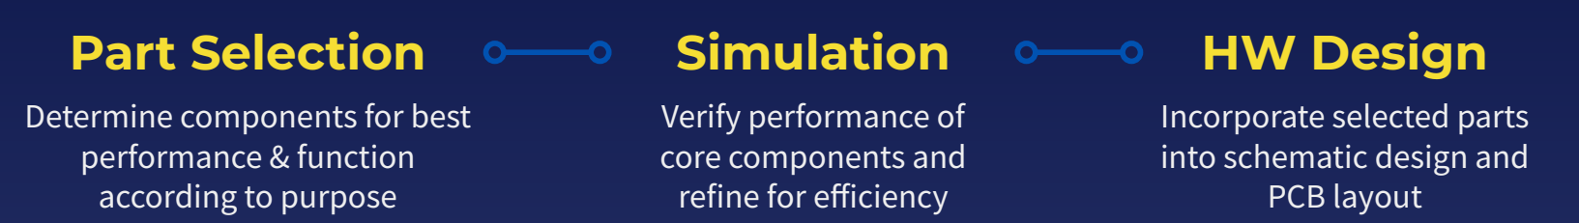
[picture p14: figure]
Part Selection; Determine components for best performance & function according to purpose; Simulation; Verify performance of core components and refine for efficiency; HW Design; Incorporate selected parts into schematic design and PCB layout

# FW Dev

Design firmware architecture for system control & UI based on existing systems

# Testing

Manufacture design & test
performance, adjust parts per testing results

03

DESIGN IMPLEMENTATION

# 4-Switch Buck-Boost Converter


# SIMULATION


# SIMULATION - INITIAL TESTING

Identify Performance Metrics; ● Input/Output voltage ripple ● Output voltage stability ● Power efficiency ● Input current draw in stress cases; Converter Operating Parameters; ● Input UVLO/OVLO hysteresis ● Switching Frequency ● Passive component values

SIMULATION - TYPICAL BUCK CASE

## General Measurements

- 0.86 Ohm Load
- Output Ripple: 10-15 mV
- Efficiency: Pout/Pin = 93.03%

SIMULATION - TYPICAL BOOST CASE

## General Measurements

- 3 Ohm Load
- Output Ripple: 0.4V P-P
- Efficiency: Pout/Pin = 88.67%

# HARDWARE OVERVIEW


# HARDWARE DESIGN

Powerpath; Converters; CPU


# SOFTWARE OVERVIEW


# SOFTWARE OVERVIEW

# SOFTWARE

DEVELOPMENT Useful UI

● OLED code displays text and other graphics.
● Screen and buttons offer valuable
information, navigation, and device control.
Programmed Reliability

● Reliability of control and information is
integral for proper consumer use.
● Development in C++ optimized for embedded
system.

# SOFTWARE

DEVELOPMENT Useful UI

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

04

FUNCTIONAL TESTING

## Initial Trials

- 12V Input boosted to 24V Output
- Vctrl monitoring for CC or CV state
- Ensuring consistent DC waveforms internal to system
- Comparing input/output range to simulation

## Peripheral Bringup

- SPI for OLED screen
- I2C for DAC and Digipot
- ADC for Sensing


## Vout

# FUNCTIONAL TESTING


Simulated Inductor Voltage | Actual Inductor Voltage

# COST ANALYSIS

PCB Components; Manufactured PCBs; TOTAL

# 5V to 60V @ 2A

# APPENDIX A:


SIMULATION - STRESS CASES

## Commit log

2021-09-20 Added diodes and N-FETs to schematics/libraries.
    [Converter.SchDoc, TopLevel.SchDoc]
2021-10-09 Create STM32 project file
    [UniversalConverter.PrjPcb]
2021-10-09 Enabled UART receiving WIP
2021-10-09 Enabled UART Receiving (for real this time)
2021-10-09 LT3790_Rev_A01
    Updated reference designators to reflect application circuit.
2021-10-12 Started simulation for inductor/switching freq.
2021-10-12 Started tests and documentation on switching freq.
2021-10-14 Increased UART BAUD, Setup framework for debugmenu commands
    BAUD up from 9600 -> 115200
    Commands added to debugmenu:
    ? - Help (Displays Menu)
    H - Echo's Hello world
